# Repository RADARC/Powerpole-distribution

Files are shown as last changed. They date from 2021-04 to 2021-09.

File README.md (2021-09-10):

# Powerpole-distribution
Anderson Powerpole distribution board with reverse polarity and over voltage protection.
Designed primarily for amateur radio use.

* 4 outputs rated at 30A with a combined 30A rating.
* TVS diodes to dissipate any transient voltage spikes.
* SCR based crowbar circuit for over voltage protection.
* Latching relay to disconnect supply if the crowbar cuircuit triggers as the input fuse may take time to blow depending on the available current from the supply.
* Diode protection around the relay and enable switch to stop the output from being enabled if the polarity is reversed.
* Input fuse for added protection.
* Output fuses to protect devices which may be rated at lower currents.

# Versions
V1.1 has the powerpole silkscreen updated to indicate the true outline of the socket. The pad and holes for sw1 have been enlarged.
# Current status
Final version of the PCB (V1.1) is complete.
Trip voltage is between 15.5V and 15.9V depending on how fast the input voltage seems to rise.
# Current and voltage meter
The circuit is designed to support the use of an ammeter in order to have a voltage and current display in the same case with the board.
A suitable meter would be https://www.aliexpress.com/item/33010218601.html. There are many sellers selling similar meters. I would suggest getting
at the very least a 50A rated one and ideally 100A as the voltage drop across the current shunt will be less.
Take note that the current shunt is wired between the netative of the input and outputs. If the power supply has a grounded negative connection then
return current can flow through ground instead of the negative causing an incorrect current reading. It is undesirable for this to happen anyway
so an incorrect current reading in this case is probably a good indication that there is something wrong anyway.
# Assembly tips
* When soldering the powerpole sockets asemble them and insert the pins and then solder to the PCB. The shells are fine with the high temperatures
during soldering. Also it helps to plug something into them when soldering the first contact to check that they are perfectly vertical. Otherwise it is not easy
to tell and you may not realise they are at an angle until something is plugged in.
* When soldering the relay, powerpole contacts and the fuse holders use plenty of heat and fine solder and try to get the solder to flow right through to the top surface.
Both surfaces are used for carrying the large currents so it's important to have a good contact between the pins and both surfaces and not rely on the small amount of
copper in the plated through hole to conduct both sides.
* The electrolytic capacitor (C3) is a bit too tall as it would require the top of the case to be quite high making removing the fuses difficult or a hole put in the lid
for the capacitor to poke though. Therefore either lie it down or just solder it to the reverse of the board as there is plenty of space under the PCB as the height
of the case is governed by the ampmeter and the cables which plug in underneath.
* A 50W soldering iron was fine for soldering all the contacts even onto the large ground planes. The only joint which was problematic was the relay contact furthest away
from the input fuse which is probably connected to the armature and sucked away a lot of the heat.
# 3D case
A case has been designed for the PCB and the current shunt and meter mentioned above.
I have made the designs public in Tinkercad so people can modify it to fit different meters or remove the option if desired.
All screws are M3 and I made made use of metal threaded inserts.  
Base - https://www.tinkercad.com/things/e5ViJ67TmCy  
Top - https://www.tinkercad.com/things/gQ1BUrXmc8q

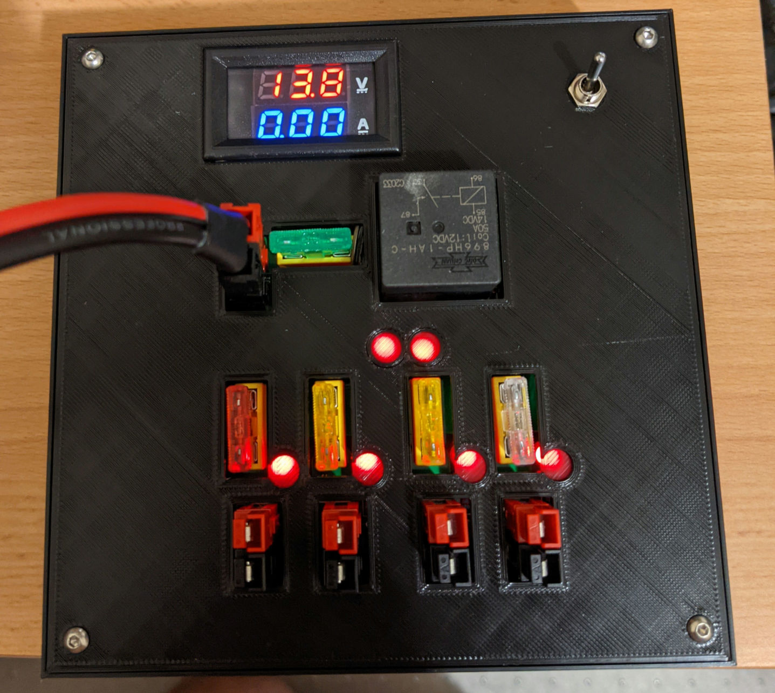
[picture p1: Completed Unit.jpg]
Image of completed unit


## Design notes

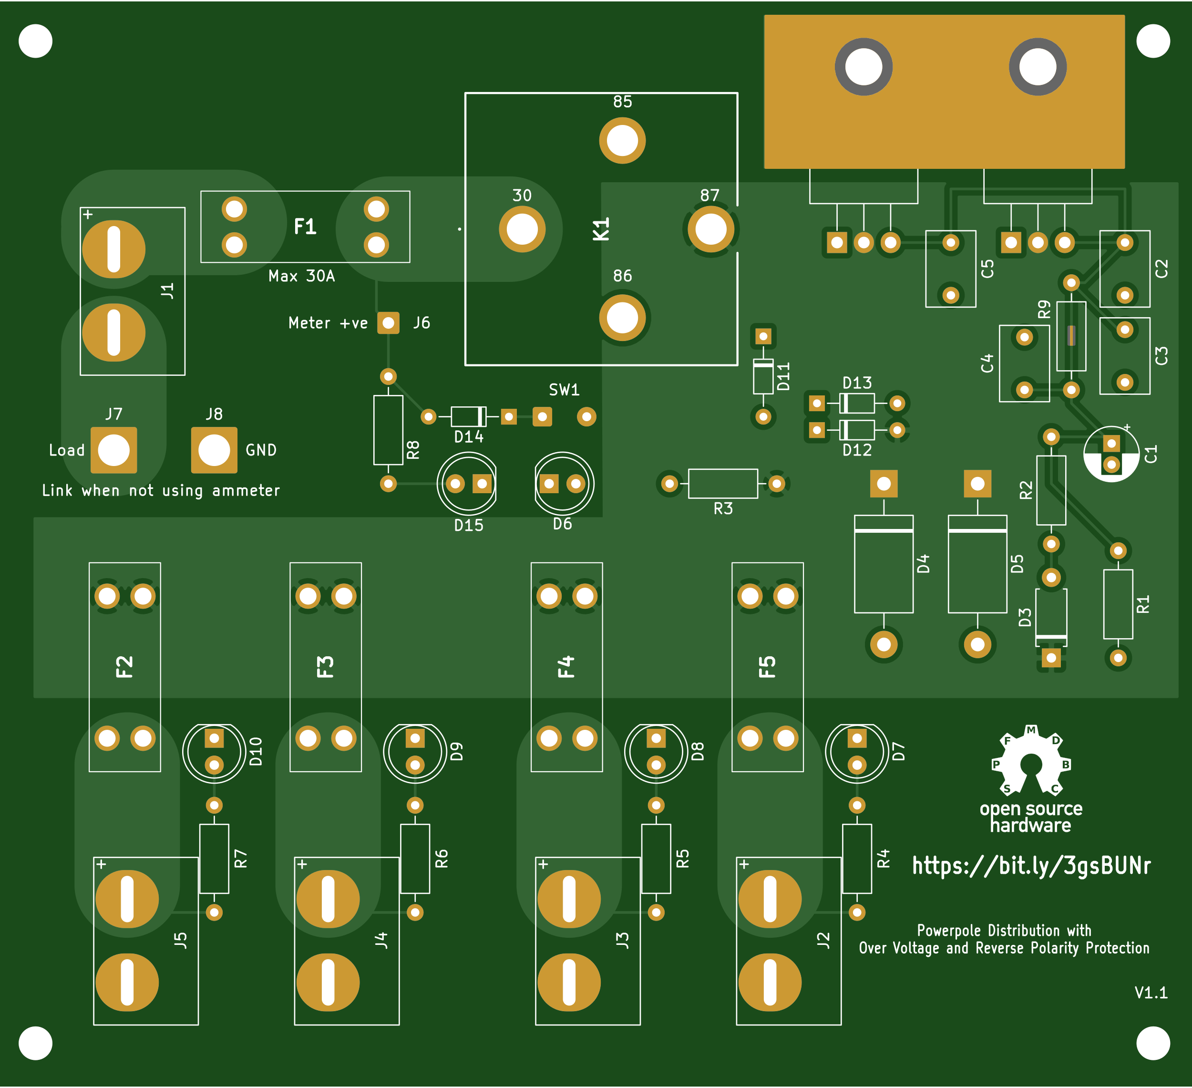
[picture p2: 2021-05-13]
pcb top.png

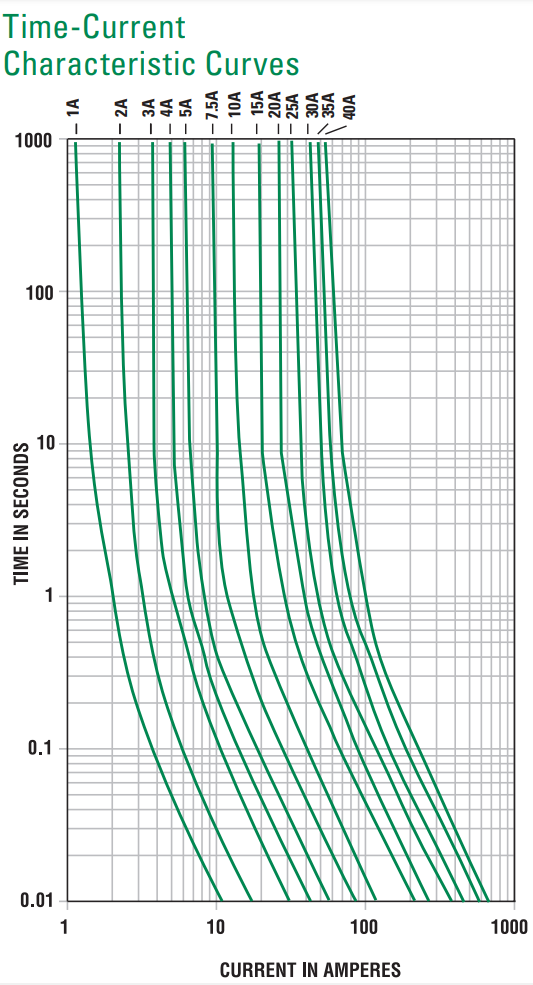
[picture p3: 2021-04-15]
Blade Fuse Current Time Graph.png

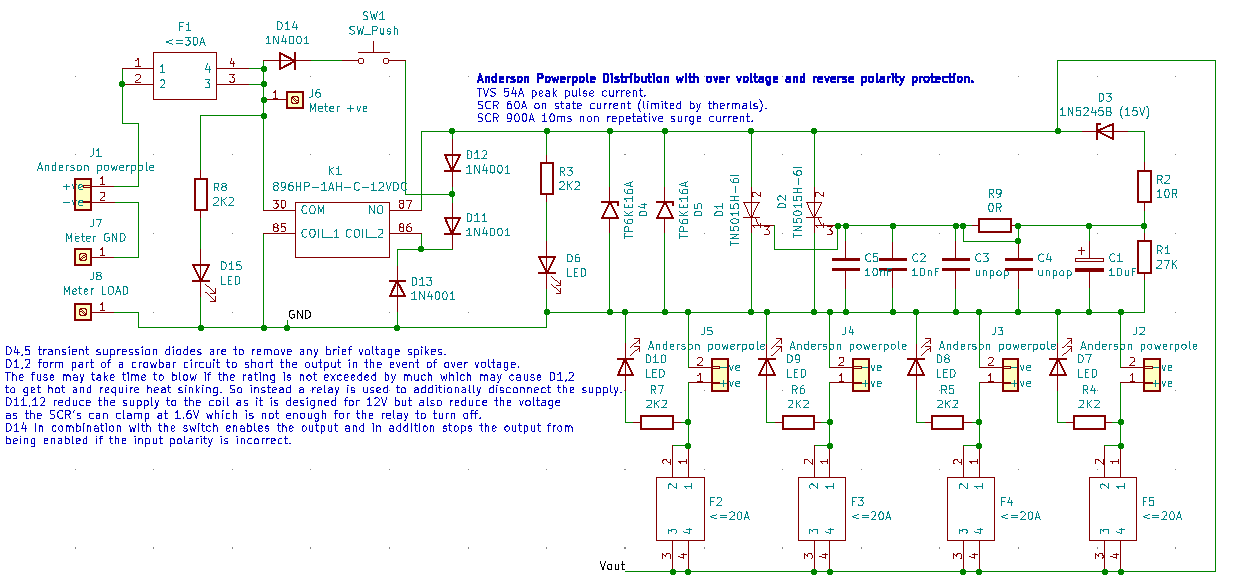
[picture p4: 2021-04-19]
Powerpole Distribution Circuit.png

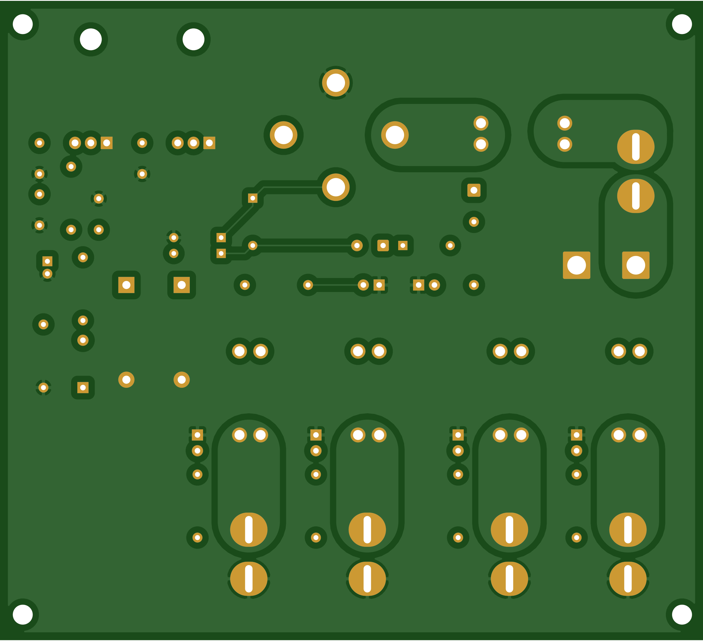
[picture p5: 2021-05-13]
pcb bottom.png

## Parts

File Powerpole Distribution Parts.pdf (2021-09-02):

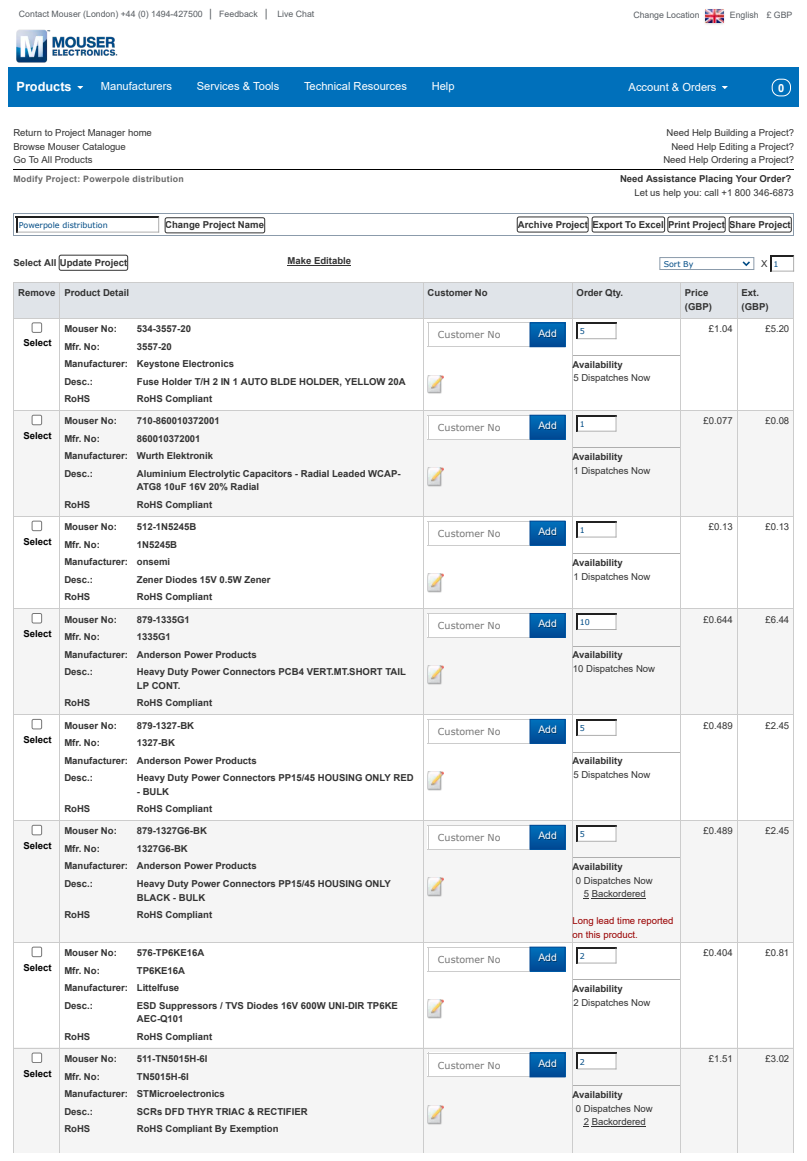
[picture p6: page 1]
Select All Update Project; Make Editable; Sort By; Modify Project: Powerpole distribution; Need Assistance Placing Your Order?; Powerpole distribution; Change Project Name; Archive Project Export To Excel Print Project Share Project; Availability 5 Dispatches Now; Availability 1 Dispatches Now; Availability 10 Dispatches Now; Availability 0 Dispatches Now 5 Backordered; Availability 2 Dispatches Now; Select; Mouser No:; Mfr. No:; Manufacturer: STMicroelectronics; Desc.: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

Return to Project Manager home (https://www.mouser.co.uk/OrderHistory/ProjectsView.aspx?Tab=6)
Browse Mouser Catalogue (https://www.mouser.co.uk/mousercatalog/)
Go To All Products (https://www.mouser.co.uk/Electronic-Components/)

Need Help Building a Project? (https://www.mouser.co.uk/help/tools/how-to-use-the-project-manager#build-project)
Need Help Editing a Project? (https://www.mouser.co.uk/help/tools/how-to-use-the-project-manager#edit-project)
Need Help Ordering a Project? (https://www.mouser.co.uk/help/tools/how-to-use-the-project-manager#order-project)

Let us help you: call +1 800 346-6873

Remove | Product Detail | Customer No | Order Qty. | Price (GBP) | Ext. (GBP)

Select | Mouser No: 534-3557-20 (https://www.mouser.co.uk/ProductDetail/534-3557-20) Mfr. No: 3557-20 (https://www.mouser.co.uk/ProductDetail/534-3557-20) Manufacturer: Keystone Electronics Desc.: Fuse Holder T/H 2 IN 1 AUTO BLDE HOLDER, YELLOW 20A (https://www.mouser.co.uk/ProductDetail/534-3557-20) RoHS RoHS Compliant | | | £1.04 | £5.20

Select | Mouser No: 710-860010372001 (https://www.mouser.co.uk/ProductDetail/710-860010372001) Mfr. No: 860010372001 (https://www.mouser.co.uk/ProductDetail/710-860010372001) Manufacturer: Wurth Elektronik Desc.: Aluminium Electrolytic Capacitors - Radial Leaded WCAP-ATG8 10uF 16V 20% Radial (https://www.mouser.co.uk/ProductDetail/710-860010372001) RoHS RoHS Compliant | | | £0.077 | £0.08

Select | Mouser No: 512-1N5245B (https://www.mouser.co.uk/ProductDetail/512-1N5245B) Mfr. No: 1N5245B (https://www.mouser.co.uk/ProductDetail/512-1N5245B) Manufacturer: onsemi Desc.: Zener Diodes 15V 0.5W Zener (https://www.mouser.co.uk/ProductDetail/512-1N5245B) RoHS RoHS Compliant | | | £0.13 | £0.13

Select | Mouser No: 879-1335G1 (https://www.mouser.co.uk/ProductDetail/879-1335G1) Mfr. No: 1335G1 (https://www.mouser.co.uk/ProductDetail/879-1335G1) Manufacturer: Anderson Power Products Desc.: Heavy Duty Power Connectors PCB4 VERT.MT.SHORT TAIL LP CONT. (https://www.mouser.co.uk/ProductDetail/879-1335G1) RoHS RoHS Compliant | | | £0.644 | £6.44

Select | Mouser No: 879-1327-BK (https://www.mouser.co.uk/ProductDetail/879-1327-BK) Mfr. No: 1327-BK (https://www.mouser.co.uk/ProductDetail/879-1327-BK) Manufacturer: Anderson Power Products Desc.: Heavy Duty Power Connectors PP15/45 HOUSING ONLY RED - BULK (https://www.mouser.co.uk/ProductDetail/879-1327-BK) RoHS RoHS Compliant | | | £0.489 | £2.45

Select | Mouser No: 879-1327G6-BK (https://www.mouser.co.uk/ProductDetail/879-1327G6-BK) Mfr. No: 1327G6-BK (https://www.mouser.co.uk/ProductDetail/879-1327G6-BK) Manufacturer: Anderson Power Products Desc.: Heavy Duty Power Connectors PP15/45 HOUSING ONLY BLACK - BULK (https://www.mouser.co.uk/ProductDetail/879-1327G6-BK) RoHS RoHS Compliant | | | £0.489 | £2.45

Long lead time reported
on this product.

Select | Mouser No: 576-TP6KE16A (https://www.mouser.co.uk/ProductDetail/576-TP6KE16A) Mfr. No: TP6KE16A (https://www.mouser.co.uk/ProductDetail/576-TP6KE16A) Manufacturer: Littelfuse Desc.: ESD Suppressors / TVS Diodes 16V 600W UNI-DIR TP6KE AEC-Q101 (https://www.mouser.co.uk/ProductDetail/576-TP6KE16A) RoHS RoHS Compliant | | | £0.404 | £0.81

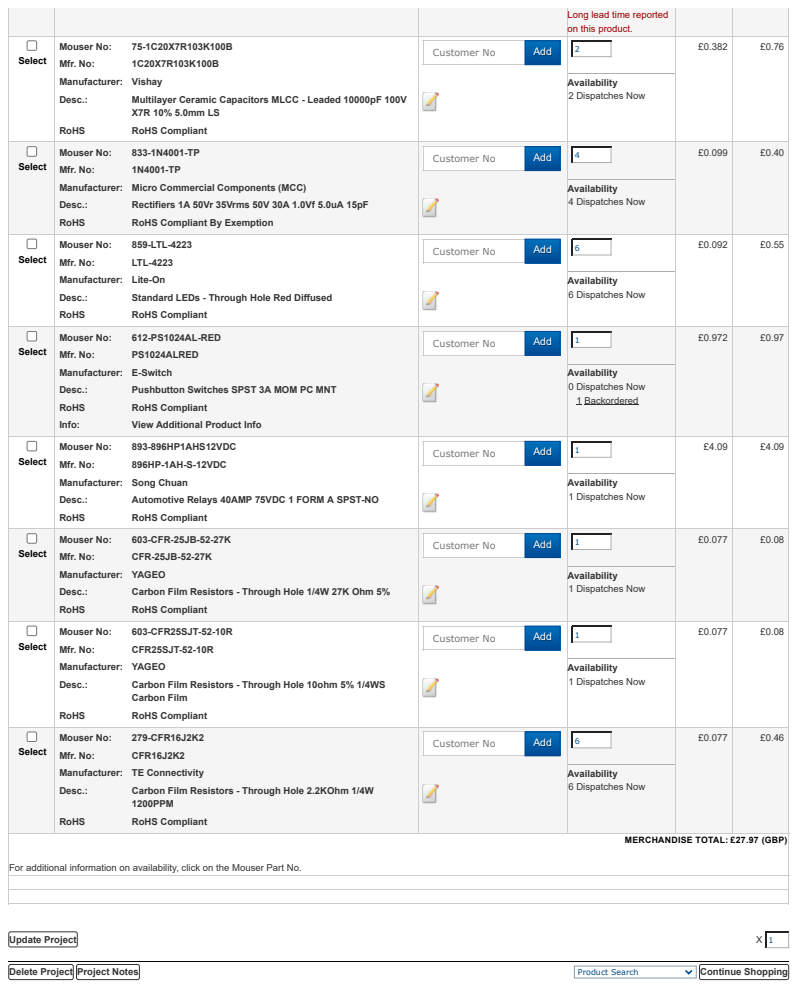
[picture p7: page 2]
Update Project; Delete Project Project Notes; Product Search; Continue Shopping; Availability 2 Dispatches Now; Availability 4 Dispatches Now; Availability 6 Dispatches Now; Availability 0 Dispatches Now 1 Backordered; Availability 1 Dispatches Now; Customer No; Add

Long lead time reported
on this product.

Select | Mouser No: 75-1C20X7R103K100B (https://www.mouser.co.uk/ProductDetail/75-1C20X7R103K100B) Mfr. No: 1C20X7R103K100B (https://www.mouser.co.uk/ProductDetail/75-1C20X7R103K100B) Manufacturer: Vishay Desc.: Multilayer Ceramic Capacitors MLCC - Leaded 10000pF 100V X7R 10% 5.0mm LS (https://www.mouser.co.uk/ProductDetail/75-1C20X7R103K100B) RoHS RoHS Compliant | £0.382 | £0.76

Select | Mouser No: 833-1N4001-TP (https://www.mouser.co.uk/ProductDetail/833-1N4001-TP) Mfr. No: 1N4001-TP (https://www.mouser.co.uk/ProductDetail/833-1N4001-TP) Manufacturer: Micro Commercial Components (MCC) Desc.: Rectifiers 1A 50Vr 35Vrms 50V 30A 1.0Vf 5.0uA 15pF (https://www.mouser.co.uk/ProductDetail/833-1N4001-TP) RoHS RoHS Compliant By Exemption | £0.099 | £0.40

Select | Mouser No: 859-LTL-4223 (https://www.mouser.co.uk/ProductDetail/859-LTL-4223) Mfr. No: LTL-4223 (https://www.mouser.co.uk/ProductDetail/859-LTL-4223) Manufacturer: Lite-On Desc.: Standard LEDs - Through Hole Red Diffused (https://www.mouser.co.uk/ProductDetail/859-LTL-4223) RoHS RoHS Compliant | £0.092 | £0.55

Select | Mouser No: 612-PS1024AL-RED (https://www.mouser.co.uk/ProductDetail/612-PS1024AL-RED) Mfr. No: PS1024ALRED (https://www.mouser.co.uk/ProductDetail/612-PS1024AL-RED) Manufacturer: E-Switch Desc.: Pushbutton Switches SPST 3A MOM PC MNT (https://www.mouser.co.uk/ProductDetail/612-PS1024AL-RED) RoHS RoHS Compliant Info: View Additional Product Info (https://www.mouser.co.uk/Cart/AdditionalProductInfo.aspx?part=5-0611-6) | £0.972 | £0.97

Select | Mouser No: 893-896HP1AHS12VDC (https://www.mouser.co.uk/ProductDetail/893-896HP1AHS12VDC) Mfr. No: 896HP-1AH-S-12VDC (https://www.mouser.co.uk/ProductDetail/893-896HP1AHS12VDC) Manufacturer: Song Chuan Desc.: Automotive Relays 40AMP 75VDC 1 FORM A SPST-NO (https://www.mouser.co.uk/ProductDetail/893-896HP1AHS12VDC) RoHS RoHS Compliant | £4.09 | £4.09

Select | Mouser No: 603-CFR-25JB-52-27K (https://www.mouser.co.uk/ProductDetail/603-CFR-25JB-52-27K) Mfr. No: CFR-25JB-52-27K (https://www.mouser.co.uk/ProductDetail/603-CFR-25JB-52-27K) Manufacturer: YAGEO Desc.: Carbon Film Resistors - Through Hole 1/4W 27K Ohm 5% (https://www.mouser.co.uk/ProductDetail/603-CFR-25JB-52-27K) RoHS RoHS Compliant | £0.077 | £0.08

Select | Mouser No: 603-CFR25SJT-52-10R (https://www.mouser.co.uk/ProductDetail/603-CFR25SJT-52-10R) Mfr. No: CFR25SJT-52-10R (https://www.mouser.co.uk/ProductDetail/603-CFR25SJT-52-10R) Manufacturer: YAGEO Desc.: Carbon Film Resistors - Through Hole 10ohm 5% 1/4WS Carbon Film (https://www.mouser.co.uk/ProductDetail/603-CFR25SJT-52-10R) RoHS RoHS Compliant | £0.077 | £0.08

Select | Mouser No: 279-CFR16J2K2 (https://www.mouser.co.uk/ProductDetail/279-CFR16J2K2) Mfr. No: CFR16J2K2 (https://www.mouser.co.uk/ProductDetail/279-CFR16J2K2) Manufacturer: TE Connectivity Desc.: Carbon Film Resistors - Through Hole 2.2KOhm 1/4W 1200PPM (https://www.mouser.co.uk/ProductDetail/279-CFR16J2K2) RoHS RoHS Compliant | £0.077 | £0.46

MERCHANDISE TOTAL: £27.97 (GBP)

For additional information on availability, click on the Mouser Part No.

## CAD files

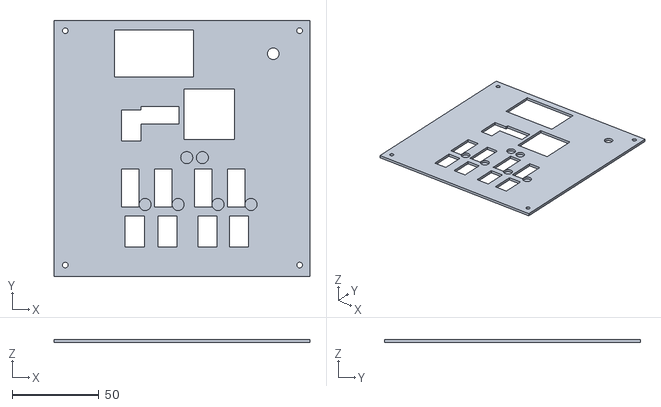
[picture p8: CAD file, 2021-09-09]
3D/Case with meter/PowerPole Case Top.stl
147.5 x 147.5 x 2.00

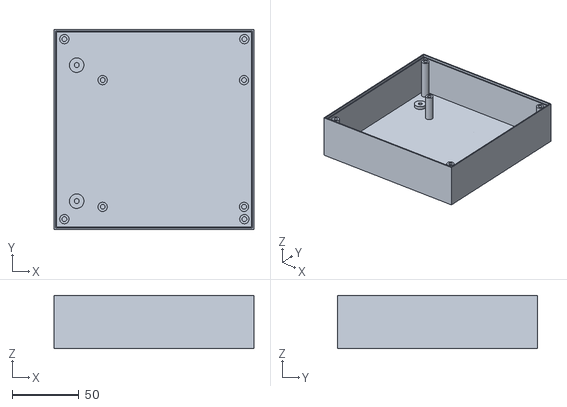
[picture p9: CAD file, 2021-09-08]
3D/Case with meter/PowerPole Case Base.stl
150.0 x 150.0 x 40.0

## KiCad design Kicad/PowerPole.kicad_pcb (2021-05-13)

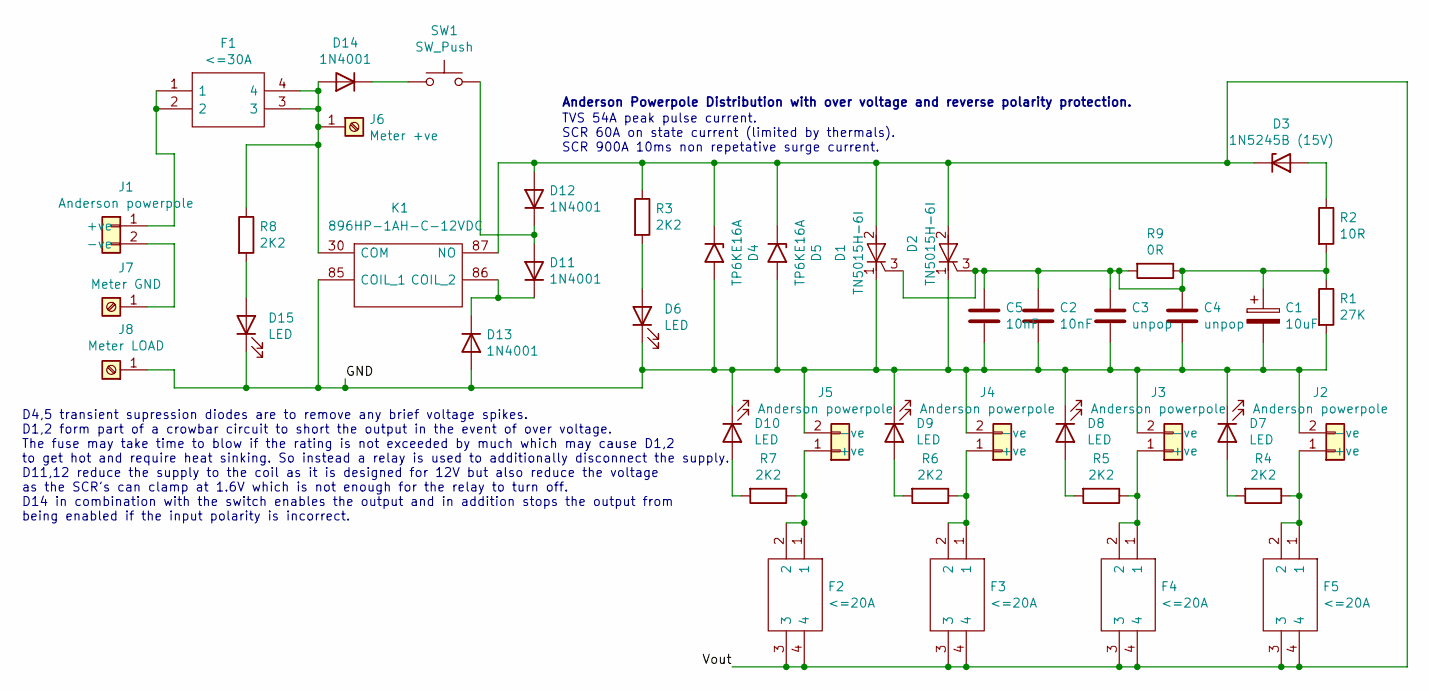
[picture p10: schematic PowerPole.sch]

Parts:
C1: 10uF; CP_Radial_D5.0mm_P2.00mm
C2, C5: 10nF; C_Rect_L7.0mm_W4.5mm_P5.00mm
C3, C4: unpop; C_Rect_L7.0mm_W4.5mm_P5.00mm
D1, D2: TN5015H-6I; TO-220-3_Horizontal_TabDown
D3: 1N5245B (15V); D_A-405_P7.62mm_Horizontal
D4, D5: TP6KE16A; D_DO-201AE_P15.24mm_Horizontal
D6, D7, D8, D9, D10, D15: LED; LED_D5.0mm
D11, D12, D13, D14: 1N4001; D_DO-34_SOD68_P7.62mm_Horizontal
F1: <=30A; 355720; Mouser Part Number 534-3557-20
F2, F3, F4, F5: <=20A; 355720; Mouser Part Number 534-3557-20
J1, J2, J3, J4, J5: Anderson powerpole; Anderson_powerpole_2w
J6: Meter +ve; SolderWire-0.5sqmm_1x01_D0.9mm_OD2.1mm
J7: Meter GND; SolderWire-2.5sqmm_1x01_D2.4mm_OD4.4mm
J8: Meter LOAD; SolderWire-2.5sqmm_1x01_D2.4mm_OD4.4mm
K1: 896HP-1AH-C-12VDC; 896HP1AHC12VDC; Mouser Part Number 893-896HP1AHC12VDC
R1: 27K; R_Axial_DIN0207_L6.3mm_D2.5mm_P10.16mm_Horizontal
R2: 10R; R_Axial_DIN0207_L6.3mm_D2.5mm_P10.16mm_Horizontal
R3, R4, R5, R6, R7, R8: 2K2; R_Axial_DIN0207_L6.3mm_D2.5mm_P10.16mm_Horizontal
R9: 0R; R_Axial_DIN0207_L6.3mm_D2.5mm_P10.16mm_Horizontal
SW1: SW_Push; SolderWire-0.25sqmm_1x02_P4.2mm_D0.65mm_OD1.7mm

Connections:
/GND: C1.2, C2.2, C3.2, C4.2, C5.2, D1.1 (K), D2.1 (K), D4.2 (A2), D5.2 (A2), D6.1 (K), D7.1 (K), D8.1 (K), D9.1 (K), D10.1 (K), D13.2 (A), D15.1 (K), J2.2 (-ve), J3.2 (-ve), J4.2 (-ve), J5.2 (-ve), J8.1, K1.85 (COIL_1), R1.2
/Vout: D1.2 (A), D2.2 (A), D3.1 (K), D4.1 (A1), D5.1 (A1), D12.2 (A), F2.3, F2.4, F3.3, F3.4, F4.3, F4.4, F5.3, F5.4, K1.87 (NO), R3.1
unnamed: C1.1, C2.1, C3.1, C4.1, C5.1, D1.3 (G), D2.3 (G), R1.1, R2.2, R9.1, R9.2
unnamed: D3.2 (A), R2.1
unnamed: D6.2 (A), R3.2
unnamed: D7.2 (A), R4.2
unnamed: D8.2 (A), R5.2
unnamed: D9.2 (A), R6.2
unnamed: D10.2 (A), R7.2
unnamed: D11.1 (K), D13.1 (K), K1.86 (COIL_2)
unnamed: D11.2 (A), D12.1 (K), SW1.2
unnamed: D14.1 (K), SW1.1
unnamed: D14.2 (A), F1.3, F1.4, J6.1, K1.30 (COM), R8.1
unnamed: D15.2 (A), R8.2
unnamed: F1.1, F1.2, J1.1 (+ve)
unnamed: F2.1, F2.2, J5.1 (+ve), R7.1
unnamed: F3.1, F3.2, J4.1 (+ve), R6.1
unnamed: F4.1, F4.2, J3.1 (+ve), R5.1
unnamed: F5.1, F5.2, J2.1 (+ve), R4.1
unnamed: J1.2 (-ve), J7.1

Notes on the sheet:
Anderson Powerpole Distribution with over voltage and reverse polarity protection.
D4,5 transient supression diodes are to remove any brief voltage spikes. D1,2 form part of a crowbar circuit to short the output in the event of over voltage. The fuse may take time to blow if the rating is not exceeded by much which may cause D1,2 to get hot and require heat sinking. So instead a 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
TVS 54A peak pulse current. SCR 60A on state current (limited by thermals). SCR 900A 10ms non repetative surge current.

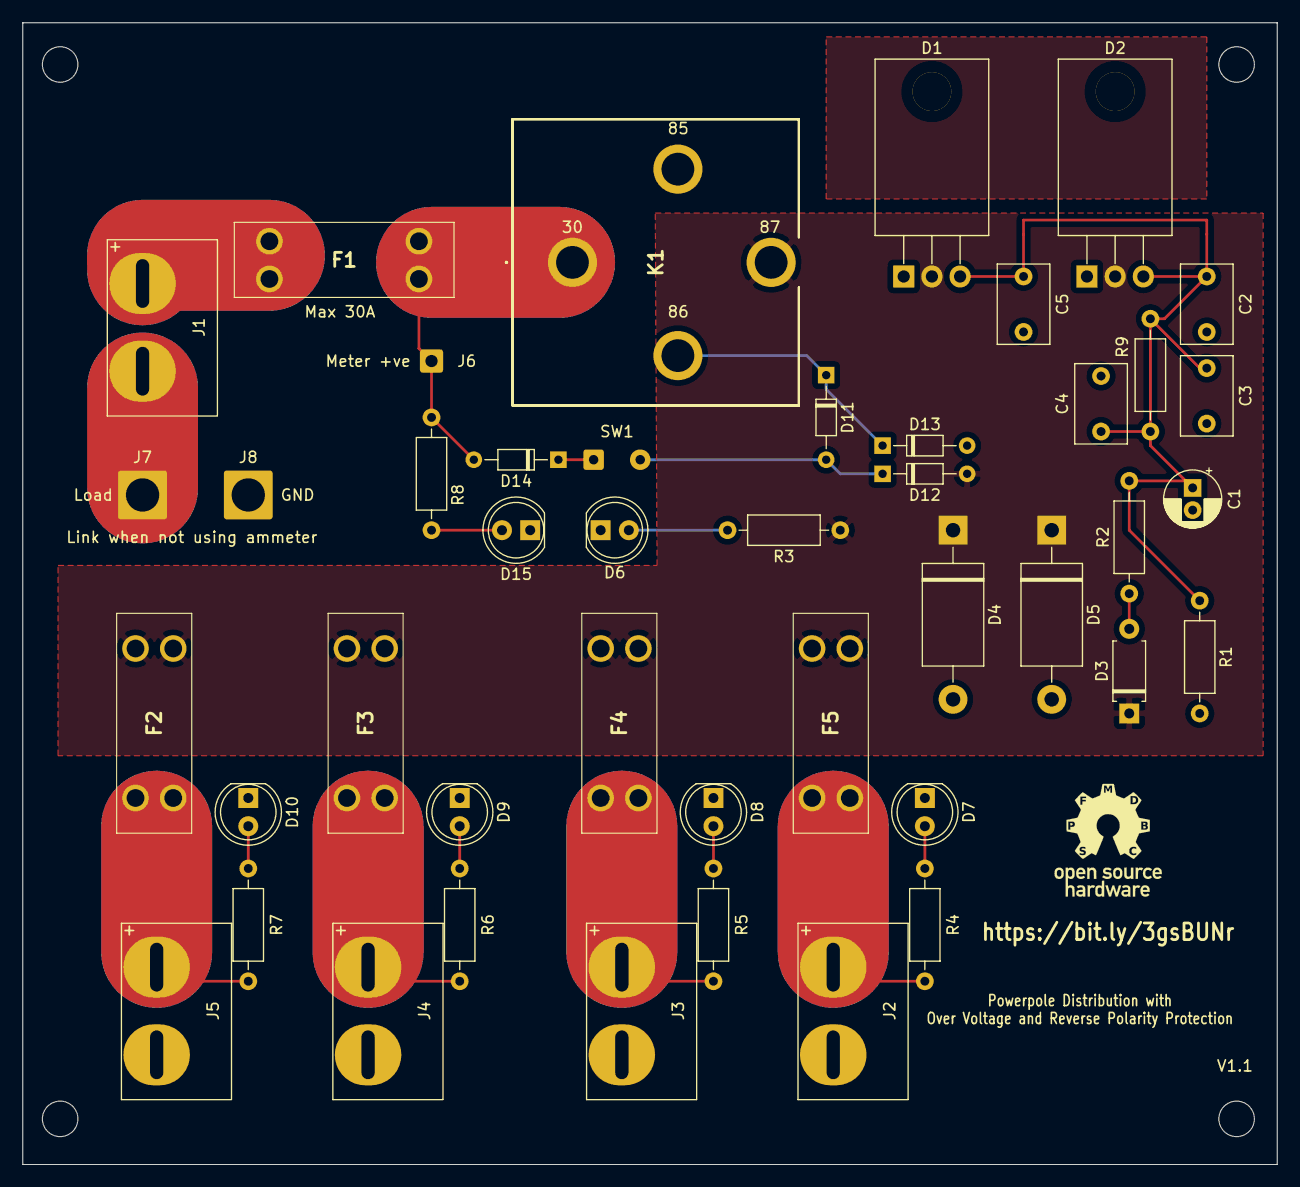
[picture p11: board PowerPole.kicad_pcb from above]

Board: 2 copper layers, 113.0 x 102.9 mm, 48 parts (0 on the bottom side), 20 nets.

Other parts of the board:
 : MountingHole_3.2mm_M3
 #2,  #3,  #4: MountingHole_3.2mm_M3

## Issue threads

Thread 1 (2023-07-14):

Very nice job and a few questions.

WildOne69, 2023-07-14:
Hi,

Very nice design and everything is laid out very nicely

a couple of questions and possible enhancements:

Why didn't you use 45A Anderson Powerpole for the input with a 45A fuse? you leave absolutely no room if the downstream devices use more than 30A combined. 45A would give a little headroom

What version of KiCAD was this created in?

Your layout is so nice, though it would be nice to turn this into an 8 port instead of 4 port by stacking the ports together closer and moving the LEDS to the end of the Anderson Powerpoles (towards the edge of the board). it looks doable, though might have to move a few other things a bit looking at the PCB's.

gblades, 2023-07-14:
Hi,
The powerpole contacts are all 1335G1's which are rated for 45A. The picture just shows a 30A fuse because that is the maximum continuous rating of the supply I was using.

It's designed in kicad 3 but should work fine in the latest version.

WildOne69, 2023-07-14:
ill try it with the current version of KiCAD I have loaded on my laptop this weekend. all the protection you have built-in is great but 4 ports just isn't enough and shrinking the whole thing down and getting 8 ports would be great. I have a commercial one that is 8 ports but has no protection other than the fuses and I don't care for it other than the size is great (it is tiny).

Any chance we could fork this and create a 8 port version?

gblades, 2023-07-14:
You are more than welcome to create a fork.

As you already have a powerpole distribution system then instead you may wish to take a look at this https://github.com/RADARC/BOBInlinePowerpole which could be inserted in front of it to add protection.

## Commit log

2021-04-17 Updated powerpole pcb footprint
2021-04-17 Added connections for power and voltage meter
2021-04-18 PCB update
    [PowerPole.kicad_pcb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]
2021-04-18 renamed pcb images
2021-04-19 Fixed value of led resistors
    [PowerPole.sch]
2021-04-19 PCB silkscreen update
    [PowerPole.kicad_pcb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]
2021-04-19 Added open source logo to pcb
    [PowerPole-B_Cu.gbr, PowerPole-B_Mask.gbr, PowerPole-Edge_Cuts.gbr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]
2021-04-24 Added mounting holes
    [PowerPole-B_Cu.gbr, PowerPole-B_Mask.gbr, PowerPole-Edge_Cuts.gbr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]
2021-04-24 Updated gerbers
    [PowerPole-B_Cu.gbr, PowerPole-B_Mask.gbr, PowerPole-B_SilkS.gbr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]
2021-04-25 Updated pcb bitmaps
2021-05-13 Updated to v1.1. powerpole sinkscreen and sw1 pads updated
    [PowerPole-B_Cu.gbr, PowerPole-B_Mask.gbr, PowerPole-B_SilkS.gbr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]
2021-09-02 Update Powerpole Distribution Parts.pdf
2021-09-08 3D case design
    [PowerPole Case Base.stl]
2021-09-09 Update case deign
    [PowerPole Case Top.stl]
2024-09-25 Update PowerPole Case Base.stl
    2mm wider supports to accept thicker metal threaded inserts
